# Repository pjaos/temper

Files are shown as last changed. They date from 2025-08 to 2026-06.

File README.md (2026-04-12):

# Temper

A Python tool for discovering temperature and humidity sensor units on the local LAN, recording their readings to a SQLite database, and visualising the data through a web-based dashboard.

---

## Overview

Temper consists of two programs that work together along with the ESP32 based hardware.

- **`temper_db`** — a background collector that listens for sensor broadcasts on the LAN and saves every reading to a local SQLite database.
- **`temper_gui`** — a browser-based dashboard (built with [NiceGUI](https://nicegui.io) and [Plotly](https://plotly.com/python/)) for plotting temperature and humidity data across any time range.

The two programs are independent. `temper_db` can run continuously as a background service while `temper_gui` is started on demand to view the data.

---

## Hardware

Temper is designed to work with TEMPER-branded sensor units that broadcast JSON payloads over UDP on the local network. Each unit reports up to four independent temperature/humidity sensor channels, along with system telemetry (RAM, disk, uptime, RSSI, battery voltage, etc.).

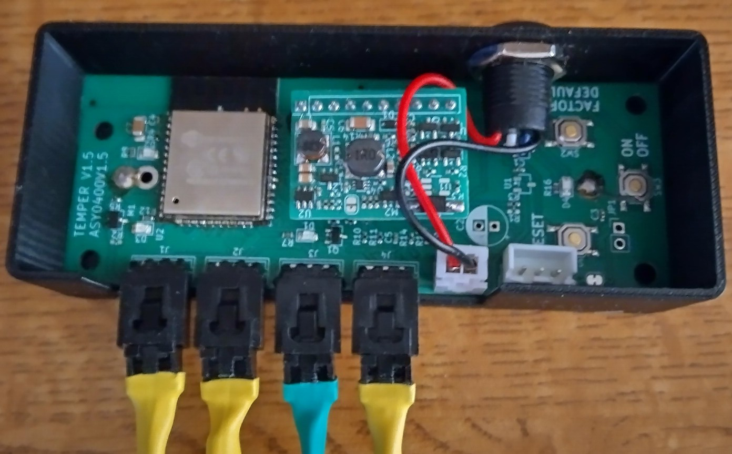
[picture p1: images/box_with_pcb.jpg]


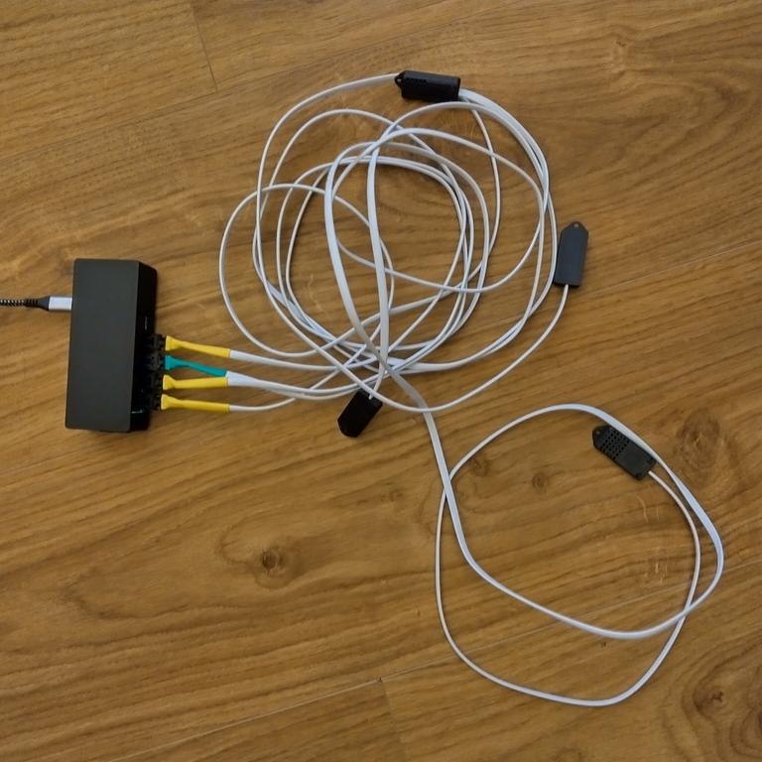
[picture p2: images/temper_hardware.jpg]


Details of the hardware including kicad schematic, PCB and BOM can be found in the hardware folder.

This hardware runs a micropython program which can be found in software/mcu folder. It listens on **UDP port 2934** and responds to *Are You There* broadcast messages with the status (temperature/humidity etc).

---

## Requirements

- Python 3.10 or later

---

## Installation

The python wheel installer file can be found in the linux folder.

### Using the bundled installer

```bash
python3 install.py linux/temper-<version>-py3-none-any.whl
```

This creates a virtual environment, installs all dependencies, and adds the `temper_db` and `temper_gui` commands to your PATH. A temper_gui launch icon is also added to you desktop.

---

## Usage

### Collector — `temper_db`

Discovers TEMPER hardware units on the local LAN and writes every received reading to the database.

```bash
python -m temper.temper_db [options]
```

| Option | Description |
|---|---|
| `-d`, `--debug` | Enable debug logging (prints each received JSON payload). |
| `-a ADDRESS`, `--address ADDRESS` | Only record data from the unit at this IP address. If omitted, all units found are recorded. |
| `-s SECONDS`, `--seconds SECONDS` | Interval between *Are You There* broadcasts (default: 10 s). |
| `--enable_auto_start` | Register the tool to start on system boot |
| `--disable_auto_start` | Un-register the tool to start on system boot |
| `--check_auto_start` | Check the running status |

**Example — record all units, broadcast every 30 seconds:**

```bash
temper_db --seconds 30
```

**Example — record only one unit:**

```bash
temper_db --address 192.168.0.99
```

**Example Running as a service**

Use the built-in boot manager to have the tool start automatically (Linux only):

```bash
temper_db --seconds 30 --enable_auto_start
```

Press **Ctrl-C** to stop.

### Dashboard — `temper_gui`

Starts a local web server and opens the dashboard in the default browser.

```bash
temper_gui [options]
```

| Option | Description |
|---|---|
| `-d`, `--debug` | Enable debug logging. |
| `-p PORT`, `--port PORT` | TCP port for the NiceGUI web server (default: 8085). |
| `-n`, `--no_web_launch` | Start the server without opening a browser tab automatically. |
| `--enable_auto_start` | Register the tool to start on system boot |
| `--disable_auto_start` | Un-register the tool to start on system boot |
| `--check_auto_start` | Check the running status |

**Browser Example**

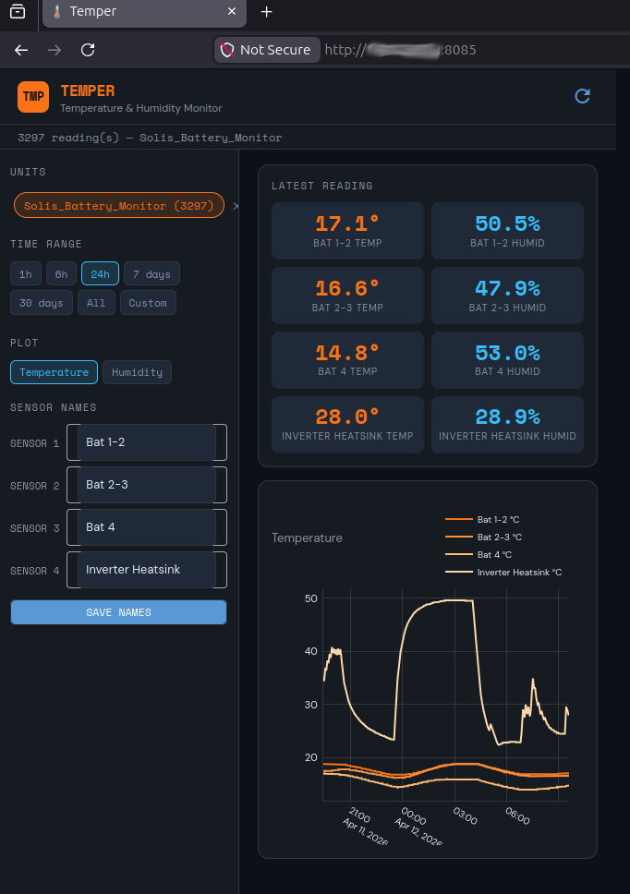
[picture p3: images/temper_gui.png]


**Example — start on a non-default port:**

```bash
temper_gui --port 9090
```

**Example — headless server (access from another device):**

```bash
temper_gui --no_web_launch
```

Then navigate to `http://<host-ip>:8085` from any browser on the same network, including a mobile phone.

**Example Running as a service**

Use the built-in boot manager to have the tool start automatically (Linux only):

```bash
temper_gui -n --enable_auto_start
```

---

## Dashboard features

The dashboard is responsive and works on both desktop and mobile browsers.

**Sidebar controls**

- **Units** — chips showing every known unit and its total reading count. Click to select a unit and load its data.
- **Time Range** — preset buttons (1h, 6h, 24h, 7 days, 30 days, All) plus a Custom option with date pickers.
- **Plot** — switch between Temperature and Humidity views.
- **Sensor Names** — rename each of the four sensor channels (e.g. *Living Room*, *Loft*, *Outside*). Names are saved to `sensor_names.json` and persist across restarts. The chart legend and stat tiles update immediately on save.

**Main area**

- **Latest Reading** — a tile grid showing the most recent temperature and humidity value for each active sensor on the selected unit.
- **Chart** — an interactive Plotly time-series plot. Hover over any point to see values for all sensors at that timestamp. Zoom and pan with standard Plotly controls.

---

## Data storage

The database and sensor name configuration are stored in:

| Platform | Path |
|---|---|
| Linux / macOS (XDG) | `~/.config/temper/` |
| Linux / macOS (fallback) / Windows | `~/.temper/` |

Files created:

| File | Contents |
|---|---|
| `temper_sensor_data.db` | SQLite database containing all sensor readings. |
| `sensor_names.json` | User-defined display names for the four sensor channels. |

### Database schema

Two tables are used:

**`units`** — one row per discovered device.

| Column | Type | Description |
|---|---|---|
| `id` | INTEGER | Primary key. |
| `unit_name` | TEXT | Unique device identifier (e.g. `TEMPER_DEV`). |
| `device_type` | TEXT | Always `SENSOR` for TEMPER hardware. |
| `product_id` | TEXT | Always `TEMPER`. |
| `ip_address` | TEXT | Last seen IP address. |
| `os` | TEXT | Firmware OS (e.g. `MicroPython`). |
| `group_name` | TEXT | Optional group label from the device. |
| `service_list` | TEXT | Services advertised by the device. |
| `first_seen` | TIMESTAMP | UTC timestamp of first contact. |
| `last_seen` | TIMESTAMP | UTC timestamp of most recent contact. |

**`sensor_readings`** — one row per received broadcast.

| Column | Type | Description |
|---|---|---|
| `id` | INTEGER | Primary key. |
| `unit_id` | INTEGER | Foreign key → `units.id`. |
| `recorded_at` | TIMESTAMP | UTC time the reading was received. |
| `rx_time_secs` | REAL | Unix timestamp from the device itself. |
| `uptime_seconds` | INTEGER | Device uptime in seconds. |
| `sensor_1_temp` … `sensor_4_temp` | REAL | Temperature readings in °C. |
| `sensor_1_humidity` … `sensor_4_humidity` | REAL | Relative humidity readings in %RH. |
| `param_3v3` | REAL | 3.3 V rail voltage. |
| `param_vbat` | REAL | Battery voltage. |
| `param_rssi` | REAL | Wi-Fi signal strength in dBm. |
| `param_board_temp` | REAL | On-board temperature sensor reading. |
| `ram_*`, `disk_*` | INTEGER | RAM and disk usage telemetry. |

### Maintenance

To delete readings older than 90 days from a Python session:

```python
from temper.temper_db import TemperDB
from unittest.mock import MagicMock
db = TemperDB.__new__(TemperDB)
db._uio = MagicMock(); db._options = None
db._db_file = TemperDB.GetDBFile()
deleted = db.prune_readings_older_than(days=90)
print(f"Deleted {deleted} rows")
```

---

## Running tests

Tests use [pytest](https://pytest.org). From the client directory:

```bash
./run_tests.sh
```

The test suite covers all database operations (`TemperDB`) including table creation, unit upsert, reading insertion, time-range filtering, latest-reading queries, and data pruning. No network access or real hardware is required.

---

## Project structure

```
temper/software/client/
├── src/
│   └── temper/
│       ├── temper_db.py        # Collector + database layer
│       └── temper_gui.py       # NiceGUI web dashboard
└── tests/
    └── test_temper_db.py       # pytest test suite
```

---

## Licence

See `LICENSE` in the repository root.

## Author

Paul Austen — [pjaos@gmail.com](mailto:pjaos@gmail.com)

## Acknowledgements

Development of this project was assisted by [Claude](https://claude.ai) (Anthropic's AI assistant),
which contributed to code review, bug identification, test generation, and this documentation.

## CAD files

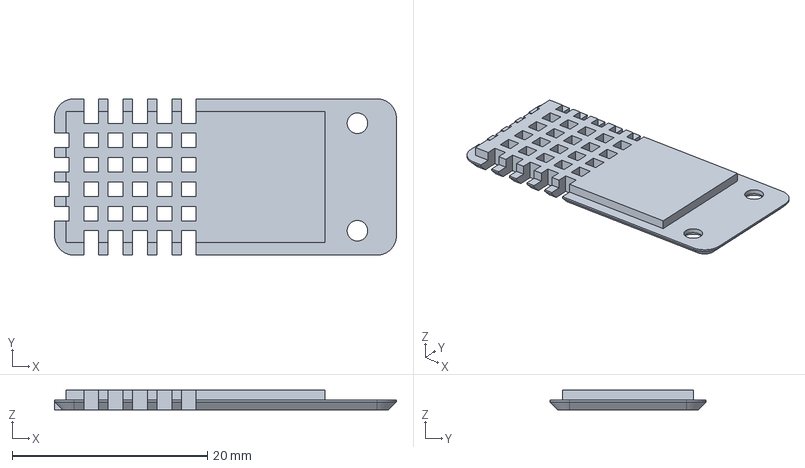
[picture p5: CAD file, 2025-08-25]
hardware/3d_printed_parts/dht22_temp_senor_case/dht22_box_top.FCStd
35.0 x 16.0 x 2.00 mm

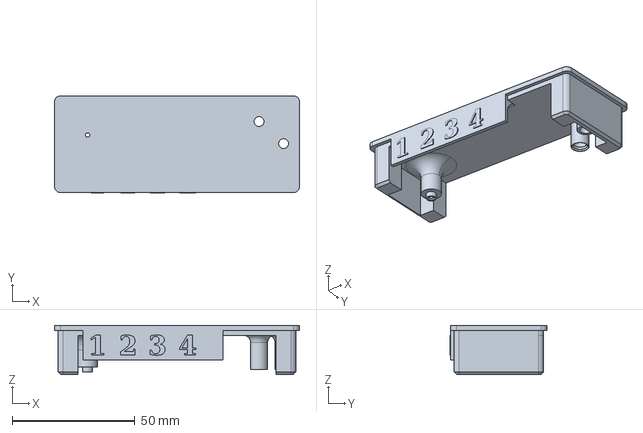
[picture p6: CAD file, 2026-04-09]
hardware/3d_printed_parts/temper_case/no_bat_top.FCStd
100.0 x 39.8 x 20.0 mm

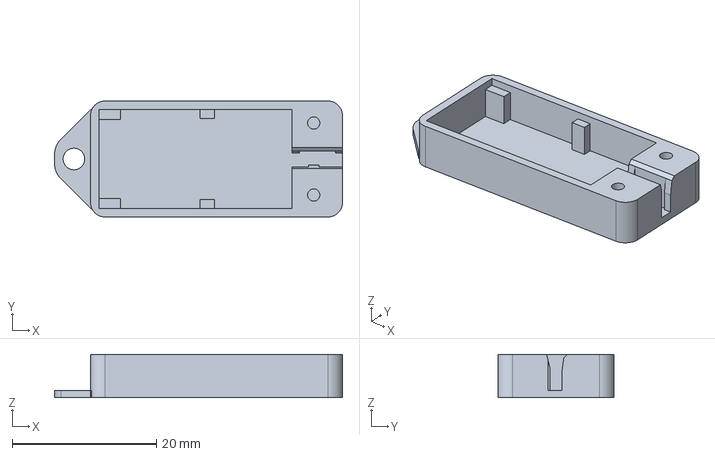
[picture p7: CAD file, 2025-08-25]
hardware/3d_printed_parts/dht22_temp_senor_case/dht22_box.FCStd
40.0 x 16.1 x 6.00 mm

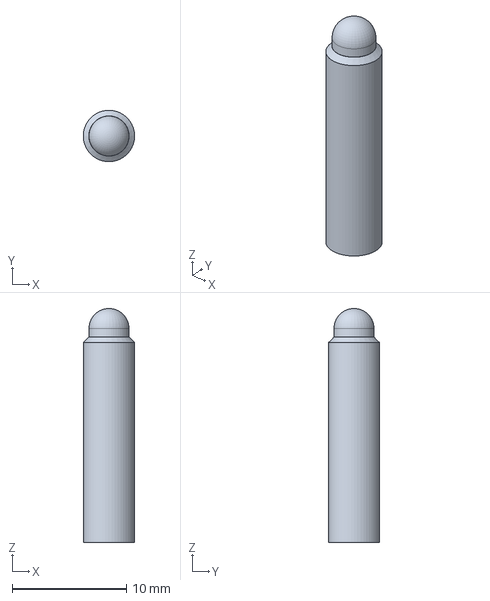
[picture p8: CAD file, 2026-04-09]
hardware/3d_printed_parts/temper_case/button.FCStd
4.50 x 4.50 x 20.5 mm

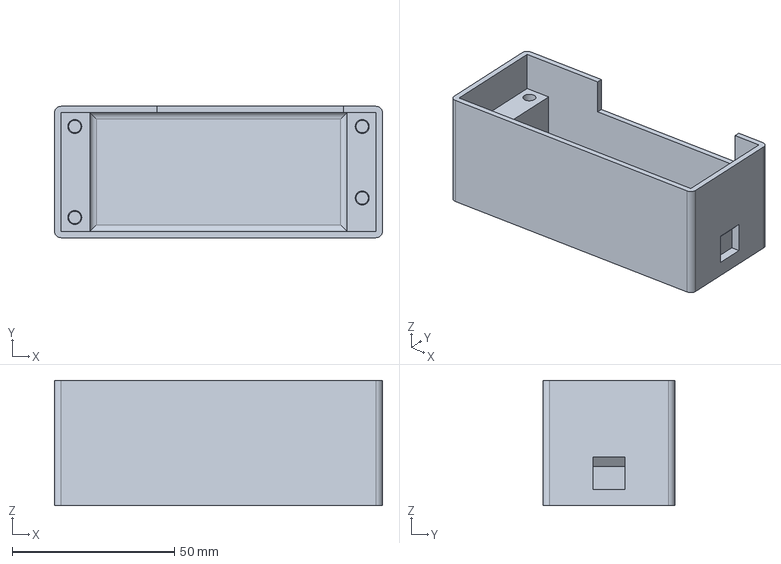
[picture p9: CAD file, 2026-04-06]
hardware/3d_printed_parts/temper_case/base.FCStd
101.0 x 40.5 x 38.5 mm

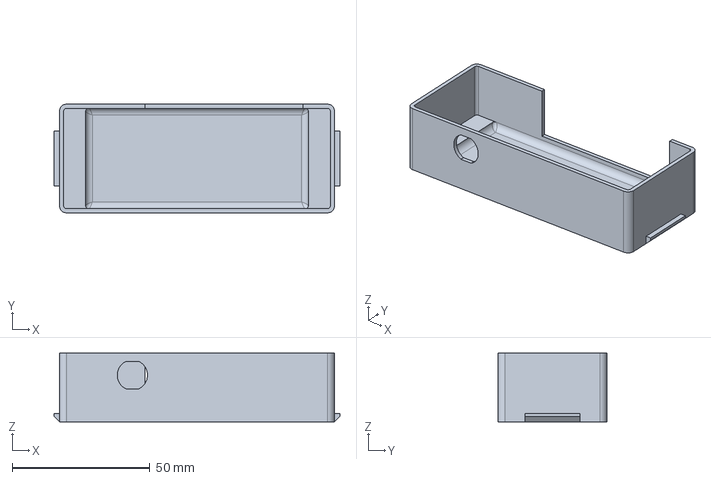
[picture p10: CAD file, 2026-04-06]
hardware/3d_printed_parts/temper_case/no_bat_base.FCStd
104.0 x 39.5 x 25.0 mm

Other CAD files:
hardware/3d_printed_parts/dht22_temp_senor_case/dht22_box.3mf
hardware/3d_printed_parts/dht22_temp_senor_case/dht22_box_top.3mf
hardware/3d_printed_parts/temper_case/base.3mf
hardware/3d_printed_parts/temper_case/button.3mf
hardware/3d_printed_parts/temper_case/no_bat_base.3mf
hardware/3d_printed_parts/temper_case/no_bat_top.3mf

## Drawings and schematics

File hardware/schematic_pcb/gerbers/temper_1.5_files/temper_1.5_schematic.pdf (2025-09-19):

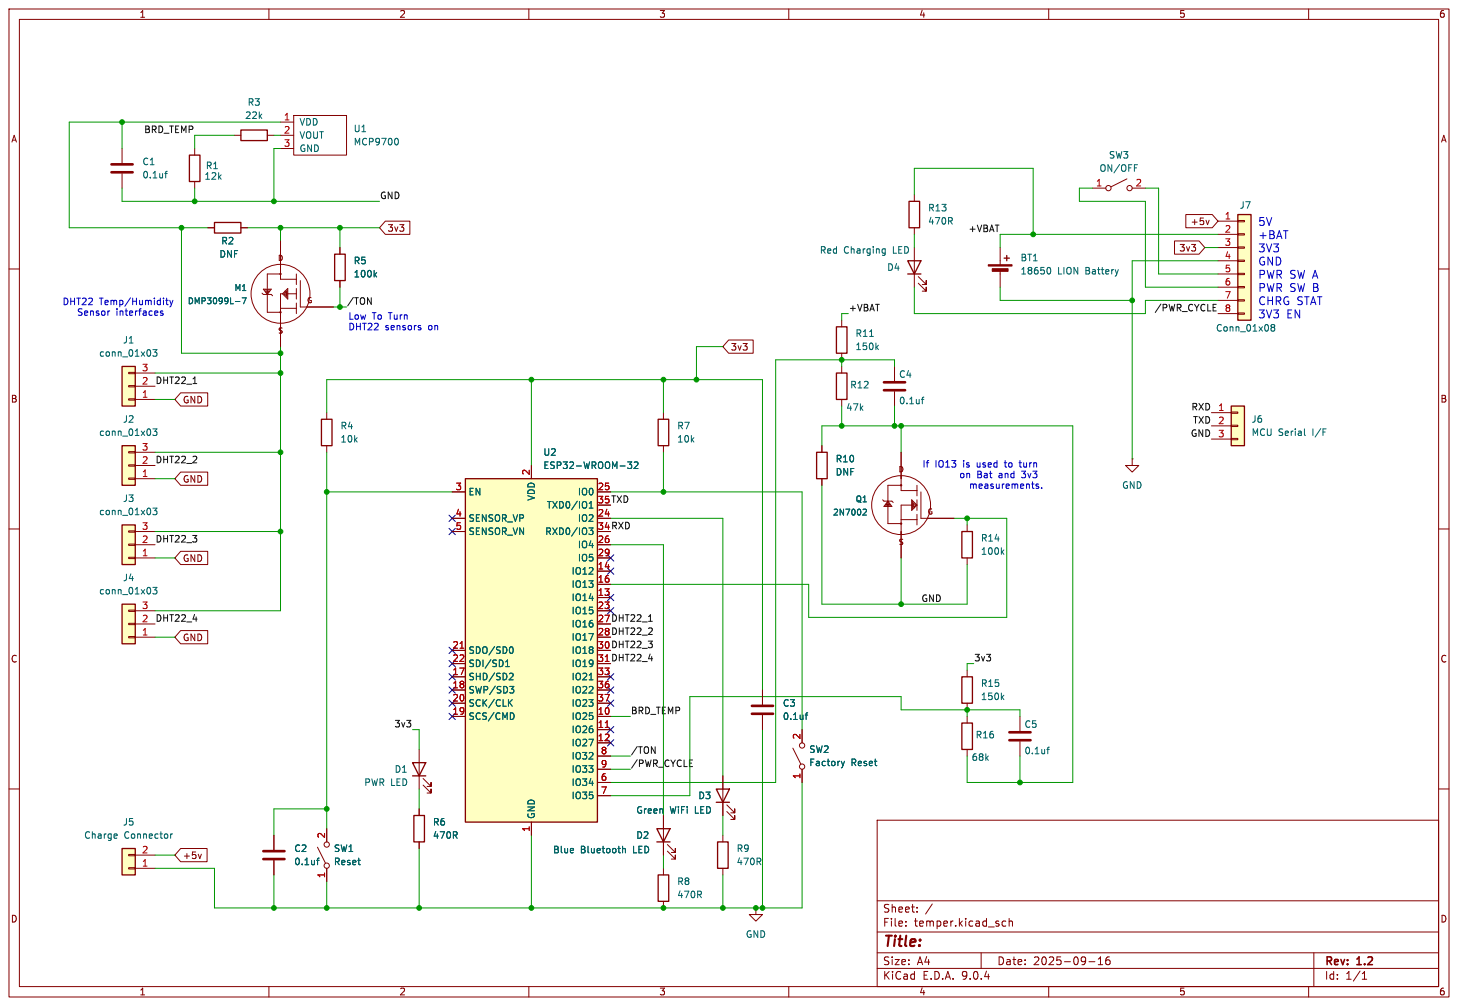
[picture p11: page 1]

If IO13 is used to turn

Id: 1/1 Title: File: temper.kicad_sch Sheet: / C2

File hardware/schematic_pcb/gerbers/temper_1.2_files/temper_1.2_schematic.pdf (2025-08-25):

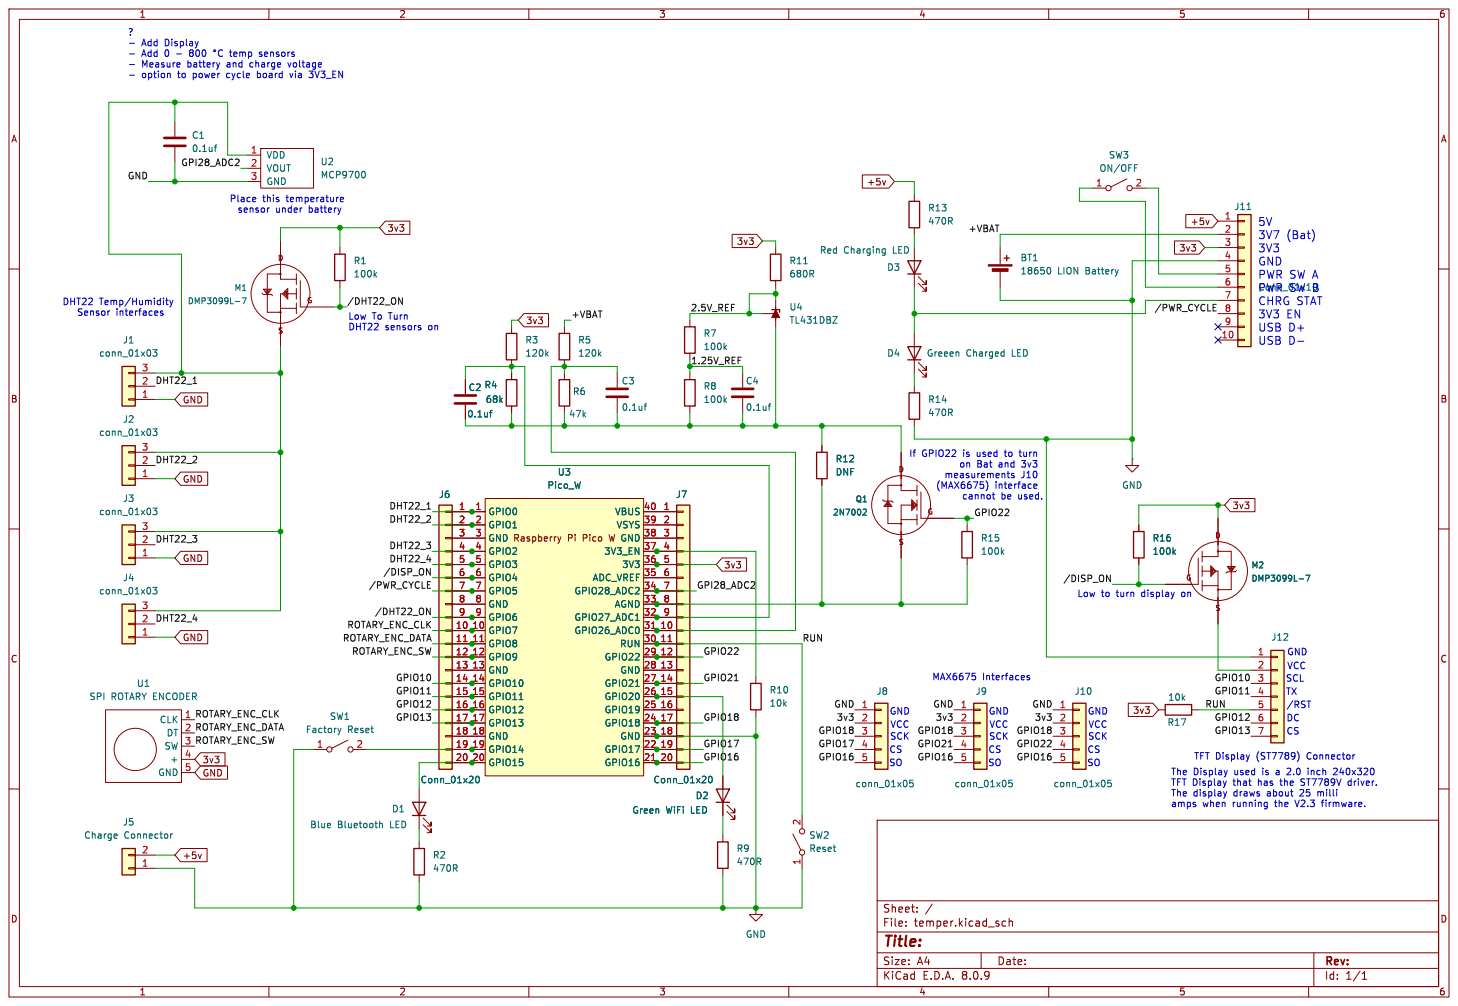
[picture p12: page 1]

- Add Display
- Add 0 - 800 þÿ°Ctemp sensors
- Measure battery and charge voltage
- option to power cycle board via 3V3_EN
S M1 DMP3099L-7 1

If GPIO22 is used to turn

cannot be used. CS

11 11 | 11 11
12 12 | 12 12
13 13 | 13 13
14 14 | 14 14
15 15 | 15 15

4 GND 5 U1 SPI ROTARY ENCODER

The Display used is a 2.0 inch 240x320 TFT Display that has the ST7789V driver. The display draws about 25 milli amps when running the V2.3 firmware.

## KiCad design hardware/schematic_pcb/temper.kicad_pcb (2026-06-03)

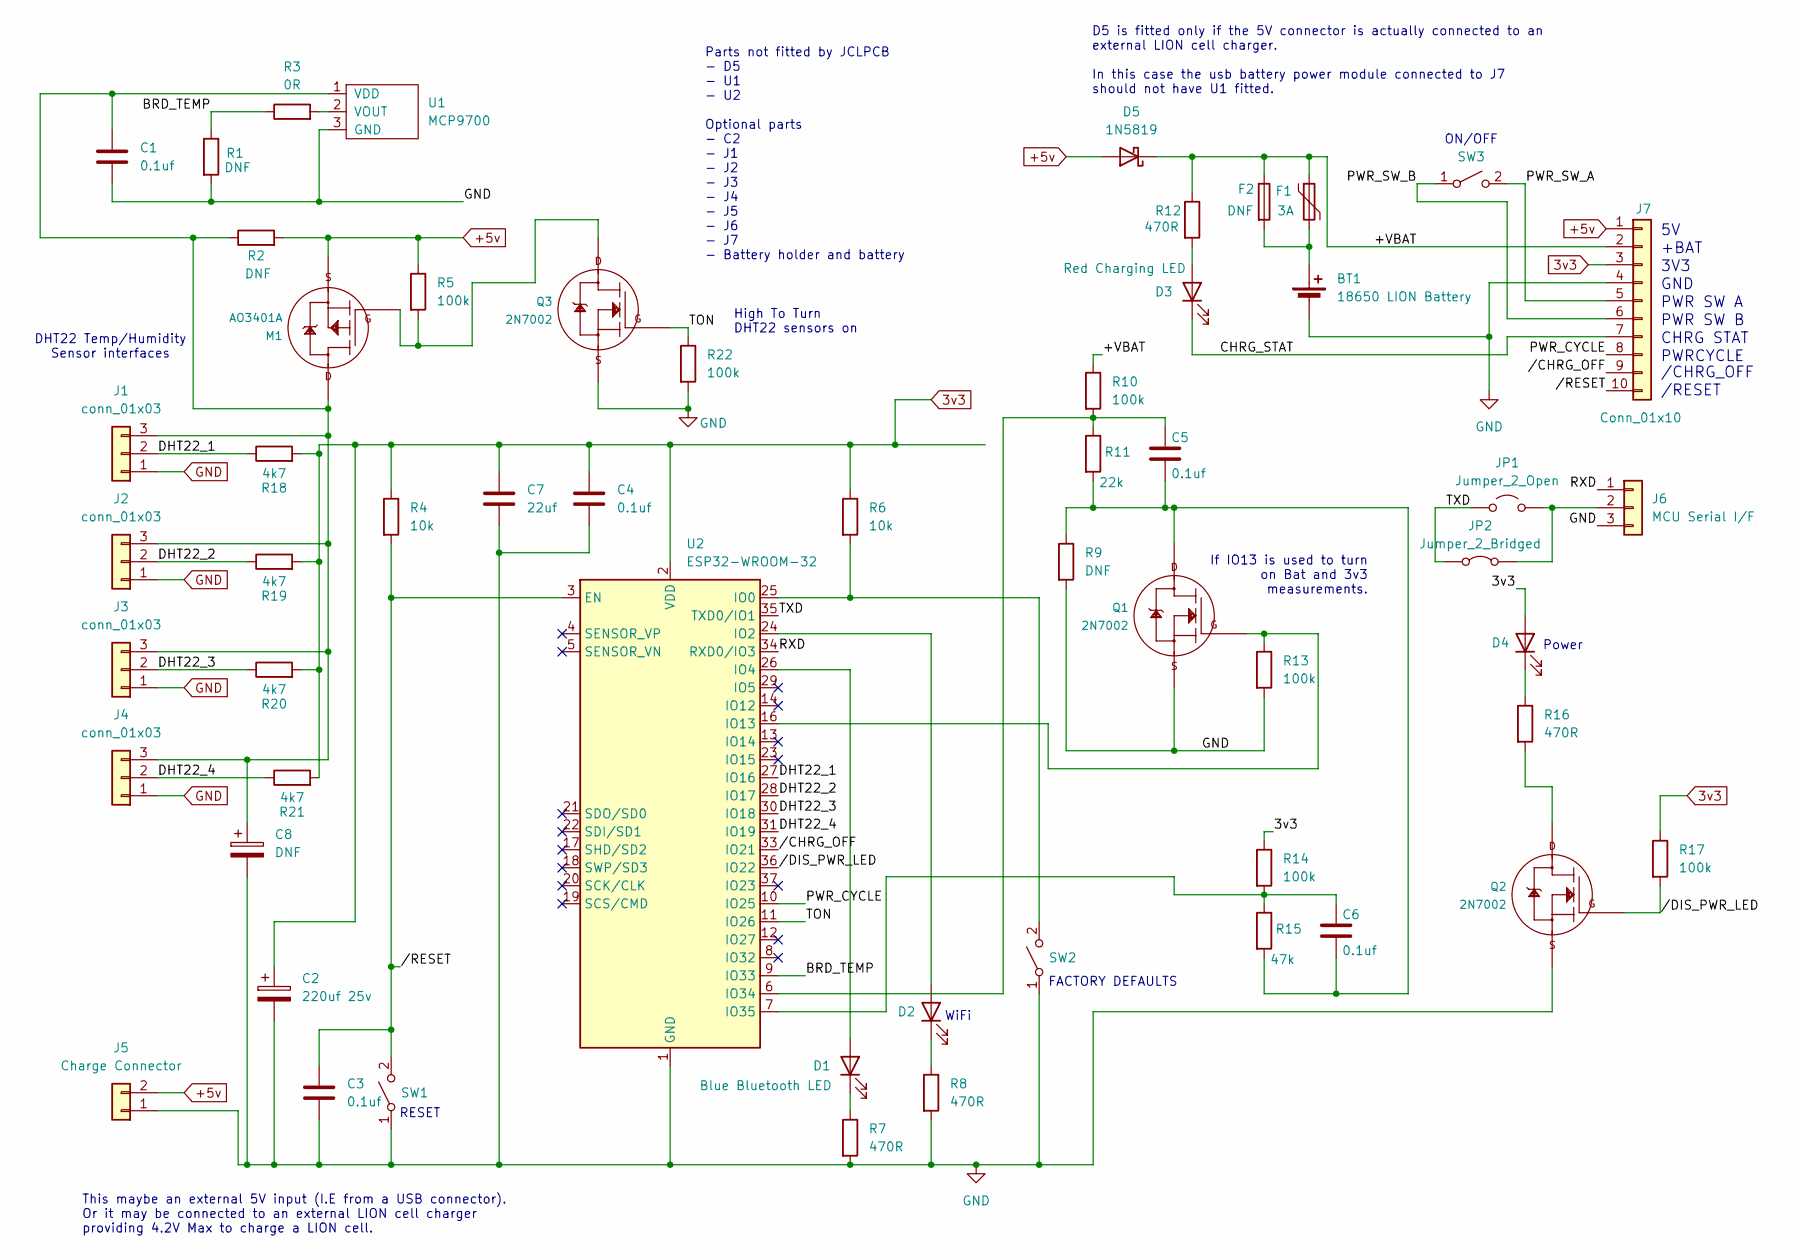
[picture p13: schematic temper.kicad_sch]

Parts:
BT1: 18650 LION Battery; 18650_26700_battery_holder
C1, C3, C4, C5, C6: 0.1uf; C_0402_1005Metric_Pad0.74x0.62mm_HandSolder; LCSC C307331
C2: 220uf 25v; CP_Radial_D6.3mm_P2.50mm
C7: 22uf; C_1206_3216Metric_Pad1.33x1.80mm_HandSolder; LCSC C12891
C8: DNF; CP_Radial_D5.0mm_P2.50mm
D1: Blue Bluetooth LED; LED_0805_2012Metric_Pad1.15x1.40mm_HandSolder; LCSC C2296
D2, D4: GreenLED; LED_0805_2012Metric_Pad1.15x1.40mm_HandSolder; LCSC C2297
D3: Red Charging LED; LED_0805_2012Metric_Pad1.15x1.40mm_HandSolder; LCSC C84256
D5: 1N5819; D_SMA_Handsoldering
F1: 3A; PTC_23mm_3mm_10.2mm_wire_spacing
F2: DNF; Scherter_OMT125
J1, J2, J3, J4: conn_01x03; JST_EH_B3B-EH-A_1x03_P2.50mm_Vertical
J5: Charge Connector; JST_EH_B2B-EH-A_1x02_P2.50mm_Vertical
J6: MCU Serial I/F; JST_EH_B3B-EH-A_1x03_P2.50mm_Vertical
J7: Conn_01x10; PinHeader_1x10_P2.54mm_Vertical
JP1: Jumper_2_Open; PinHeader_1x02_P2.54mm_Vertical
JP2: Jumper_2_Bridged; SolderJumper-2_P1.3mm_Bridged_RoundedPad1.0x1.5mm
M1: AO3401A; SOT-23-3; LCSC C15127
Q1, Q2, Q3: 2N7002; SOT-23-3; LCSC C8545
R1, R2, R9: DNF; R_0402_1005Metric_Pad0.72x0.64mm_HandSolder
R3: 0R; R_0402_1005Metric_Pad0.72x0.64mm_HandSolder; LCSC C17168
R4, R6: 10k; R_0402_1005Metric_Pad0.72x0.64mm_HandSolder; LCSC C25744
R5, R10, R13, R14, R17, R22: 100k; R_0402_1005Metric_Pad0.72x0.64mm_HandSolder; LCSC C25741
R7, R8, R12, R16: 470R; R_0402_1005Metric_Pad0.72x0.64mm_HandSolder; LCSC C23179
R11: 22k; R_0402_1005Metric_Pad0.72x0.64mm_HandSolder; LCSC C25768
R15: 47k; R_0402_1005Metric_Pad0.72x0.64mm_HandSolder; LCSC C25792
R18, R19, R20, R21: 4k7; R_0402_1005Metric_Pad0.72x0.64mm_HandSolder; LCSC C25900
SW1, SW2, SW3: tactsw; SW_SPST_SKQG_WithoutStem; LCSC C318884
U1: MCP9700; SOT-23-3
U2: ESP32-WROOM-32

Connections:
3v3: C2.1, C4.1, C7.1, D4.2 (A), J7.3, R4.1, R6.1, R14.1, R17.1, R18.2, R19.2, R20.2, R21.2, U2.2 (VDD)
+5v: D5.2 (A), J5.2, J7.1, M1.2 (S1), R2.2, R5.1
/+VBAT: D5.1 (K), F1.1, F2.1, J7.2, R10.1, R12.1
/BRD_TEMP: R1.1, R3.1, U2.9 (IO33)
/CHRG_STAT: D3.1 (K), J7.7
/DHT22_1: J1.2, R18.1, U2.27 (IO16)
/DHT22_2: J2.2, R19.1, U2.28 (IO17)
/DHT22_3: J3.2, R20.1, U2.30 (IO18)
/DHT22_4: J4.2, R21.1, U2.31 (IO19)
/PWR_CYCLE: J7.8, U2.10 (IO25)
/PWR_SW_A: J7.5, SW3.2 (B)
/PWR_SW_B: J7.6, SW3.1 (A)
/RXD: J6.1, U2.34 (RXD0/IO3)
/TON: Q3.1 (G), R22.1, U2.11 (IO26)
/TXD: JP1.1 (A), JP2.1 (A), U2.35 (TXD0/IO1)
//CHRG_OFF: J7.9, U2.33 (IO21)
//DIS_PWR_LED: Q2.1 (G), R17.2, U2.36 (IO22)
//RESET: C3.1, J7.10, R4.2, SW1.2 (B), U2.3 (EN)
GND: BT1.2 (-), C1.2, C2.2, C3.2, C4.2, C7.2, C8.2, J1.1, J2.1, J3.1, J4.1, J5.1, J6.3, J7.4, Q1.2 (S), Q2.2 (S), Q3.2 (S), R1.2, R7.2, R8.2, R9.2, R13.2, R22.2, SW1.1 (A), SW2.1 (A), U1.3 (GND), U2.1 (GND), U2.15 (GND), U2.38 (GND), U2.39 (GND)
unnamed: BT1.1 (+), F1.2, F2.2
unnamed: D1.2 (A), U2.26 (IO4)
unnamed: D1.1 (K), R7.1
unnamed: D2.2 (A), U2.24 (IO2)
unnamed: D2.1 (K), R8.1
unnamed: D3.2 (A), R12.2
unnamed: D4.1 (K), R16.1
unnamed: C1.1, C8.1, J1.3, J2.3, J3.3, J4.3, M1.3 (D1), R2.1, U1.1 (VDD)
unnamed: J6.2, JP1.2 (B), JP2.2 (B)
unnamed: M1.1 (G1), Q3.3 (D), R5.2
unnamed: C5.2, C6.2, Q1.3 (D), R9.1, R11.2, R15.2
unnamed: Q1.1 (G), R13.1, U2.16 (IO13)
unnamed: Q2.3 (D), R16.2
unnamed: R6.2, SW2.2 (B), U2.25 (IO0)
unnamed: R3.2, U1.2 (VOUT)
unnamed: C5.1, R10.2, R11.1, U2.6 (IO34)
unnamed: C6.1, R14.2, R15.1, U2.7 (IO35)

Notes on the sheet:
+BAT
RESET
If IO13 is used to turn on Bat and 3v3 measurements.
CHRG STAT
Parts not fitted by JCLPCB - D5 - U1 - U2 Optional parts - C2 - J1 - J2 - J3 - J4 - J5 - J6 - J7 - Battery holder and battery
/RESET
Power
High To Turn DHT22 sensors on
/CHRG_OFF
This maybe an external 5V input (I.E from a USB connector). Or it may be connected to an external LION cell charger providing 4.2V Max to charge a LION cell.
FACTORY DEFAULTS
GND
PWR SW A
PWR SW B
DHT22 Temp/Humidity Sensor interfaces
ON/OFF
3V3
PWRCYCLE
WiFi
D5 is fitted only if the 5V connector is actually connected to an external LION cell charger. In this case the usb battery power module connected to J7 should not have U1 fitted.

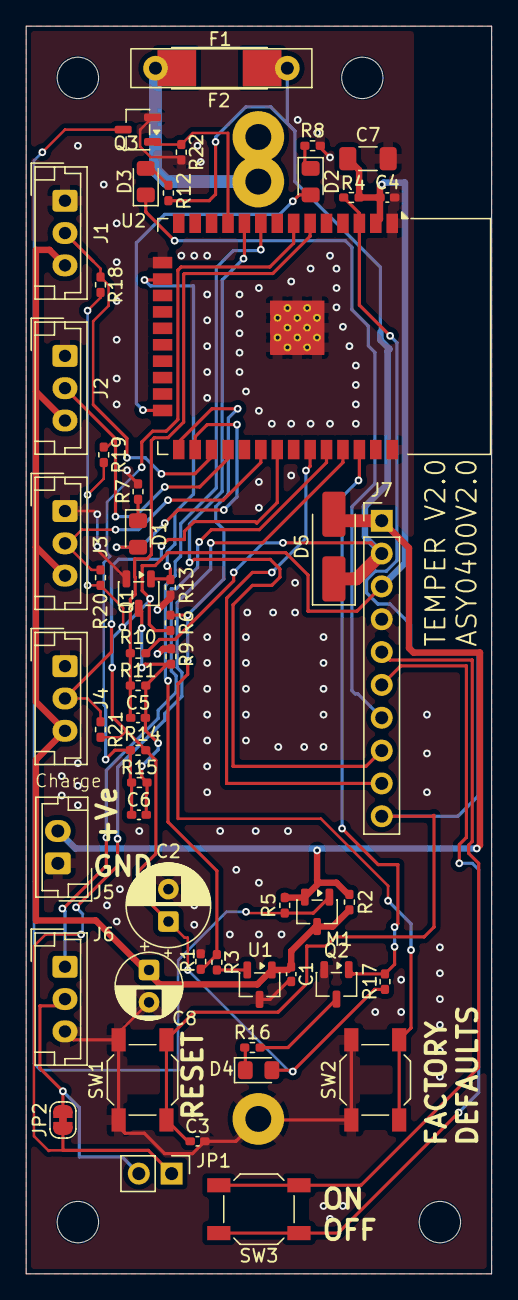
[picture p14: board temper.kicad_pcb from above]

Board: 2 copper layers, 36.0 x 96.5 mm, 60 parts (0 on the bottom side), 36 nets.

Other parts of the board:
H1, H2, H3, H4: MountingHole_3.2mm_M3

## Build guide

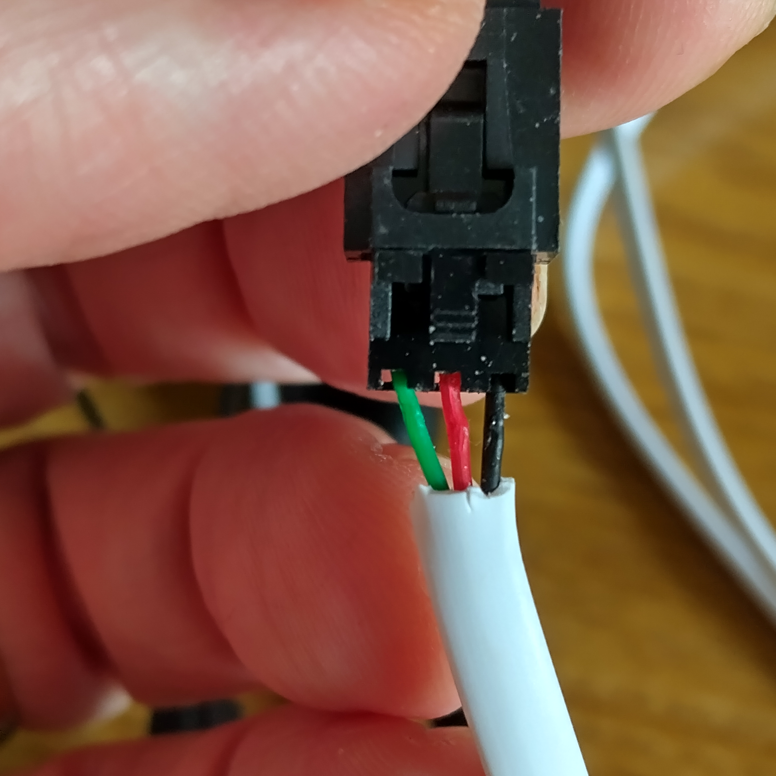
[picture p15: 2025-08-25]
doc/molex_2543_connector_wiring.jpg

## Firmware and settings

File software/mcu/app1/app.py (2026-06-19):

import asyncio
import gc
from time import time
import sys, io

from lib.uo import UO
from lib.config import MachineConfig
from lib.ydev import YDev
from lib.base_machine import BaseMachine

from machine import ADC, Pin
import dht

SHOW_MESSAGES_ON_STDOUT = True  # Turning this off will stop messages being sent on the serial port and will reduce CPU usage.
WDT_TIMEOUT_MSECS = 8300        # Note that 8388 is the max WD timeout value on pico W hardware.


class ThisMachineConfig(MachineConfig):
    """@brief Defines the config specific to this machine."""

    # Note that
    # MachineConfig.RUNNING_APP_KEY and
    # MachineConfig.WIFI_KEY will added automatically so we only need
    # to define keys that are specific to this machine type here.

    DEFAULT_CONFIG = {YDev.ACTIVE: True,
                      YDev.AYT_TCP_PORT_KEY: 2934,               # The UDP port we expect to receive an AYT UDP broadcast message
                      YDev.OS_KEY: "MicroPython",
                      YDev.UNIT_NAME_KEY: "TEMPER_DEV",          # This can be used to identify device, probably user configurable.
                      YDev.PRODUCT_ID_KEY: "TEMPER",             # This is fixed for the product, probably during MFG.
                      YDev.DEVICE_TYPE_KEY: "SENSOR",            # This is fixed for the product, probably during MFG.
                      YDev.SERVICE_LIST_KEY: "web:80",           # A service name followed by the TCPIP port number this device presents the service on.
                      YDev.GROUP_NAME_KEY: ""                    # Used put devices in a group for mild isolation purposes.
                      }

    def __init__(self):
        super().__init__(ThisMachineConfig.DEFAULT_CONFIG)


async def start(runningAppKey, configFilename):
    """@brief The app entry point.
       @param runningAppKey The KEY in the config dict that holds the current running app.
       @param configFilename The name of the config file. This sits in / on flash."""
    MachineConfig.RUNNING_APP_KEY = runningAppKey
    MachineConfig.CONFIG_FILENAME = configFilename
    file_path = __file__
    if file_path.startswith('app1'):
        active_app = 1

    elif file_path.startswith('app2'):
        active_app = 2

    else:
        raise Exception(f"App path not /app1 or /app2: {file_path}")

    if SHOW_MESSAGES_ON_STDOUT:
        uo = UO(enabled=True, debug_enabled=True)
        uo.info("Started app")
        uo.info("Running app{}".format(active_app))
    else:
        uo = None

    machine_config = ThisMachineConfig()
    this_machine = ThisMachine(uo, machine_config)
    this_machine.start()


class ThisMachine(BaseMachine):
    """@brief Implement functionality required by this project."""

    ADC_CODES_TO_MV             = 14508  # Arrived at empirically by measuring the ADC voltage @ 25C
    MCP9700_VOUT_0C             = 0.5
    MCP9700_TC                  = 0.01

    PARAM_3V3 = "PARAM_3V3"
    PARAM_VBAT = "PARAM_VBAT"
    PARAM_BOARD_TEMP = "PARAM_BOARD_TEMP"
    PARAM_SENSOR_1_TEMP = "PARAM_SENSOR_1_TEMP"
    PARAM_SENSOR_1_HUMIDITY = "PARAM_SENSOR_1_HUMIDITY"
    PARAM_SENSOR_2_TEMP = "PARAM_SENSOR_2_TEMP"
    PARAM_SENSOR_2_HUMIDITY = "PARAM_SENSOR_2_HUMIDITY"
    PARAM_SENSOR_3_TEMP = "PARAM_SENSOR_3_TEMP"
    PARAM_SENSOR_3_HUMIDITY = "PARAM_SENSOR_3_HUMIDITY"
    PARAM_SENSOR_4_TEMP = "PARAM_SENSOR_4_TEMP"
    PARAM_SENSOR_4_HUMIDITY = "PARAM_SENSOR_4_HUMIDITY"
    PARAM_RSSI = "PARAM_RSSI"
    EXCEPTION_TEXT = "EXCEPTION_TEXT"
    DETECTED_SENSOR_LIST = "DETECTED_SENSOR_LIST"

    MIN_DHT22_TEMP = -40.0
    MAX_DHT22_TEMP = 80.0

    def __init__(self, uo, machine_config):
        super().__init__(uo, machine_config)
        self._startTime = time()
        self._ydev = None
        self._sensor_power_pin = Pin(26, Pin.OUT, value=0)
        self._sensor_read_error_count=0

        # Enable watchdog timer here if required.
        # If the WiFi goes down then we can
        # drop out to the REPL prompt.
        # The WDT will then trigger a reboot.
        # self._wdt = WDT(timeout=WDT_TIMEOUT_MSECS)

        # Ensure the device name is present in the machine config
        # This is the same value that used to be hard coded.
        if not self._machine_config.is_parameter(YDev.UNIT_NAME_KEY):
            self._machine_config.set(YDev.UNIT_NAME_KEY, "TEMPER_DEV")

    def start(self):
        self.show_ram_info()

        # Connect this machine to a WiFi network.
        # Note that the WiFi setup claims two GPIO pins. See _sta_connect_wifi doc for more info.
        self._sta_connect_wifi(wifi_setup_gpio=0, wifi_led_gpio=2, bluetooth_led_gpio=4)

        # Start task that looks for user press of the reset to defaults button press
        asyncio.create_task(self._check_factory_Defaults_task())

        # Task that will return JSON messages to the YDev server.
        self._ydev = YDev(self._machine_config)
        asyncio.create_task(self._ydev.listen())

        # Run the web server. This is used for upgrades and also to present
        # a local webserver to allow users to interact with the device.
        from lib.webserver import WebServer
        self._web_server = WebServer(self._machine_config,
                               self._startTime,
                               uo=self._uo)

        # Call the app task to execute your projects functionality.
        asyncio.create_task(self.app_task())

        self._web_server.run()

    async def power_cycle_temp_sensors(self, delay=10.0):
        # Set TON low to remove power to the temp sensors
        self._sensor_power_pin.value(0)
        await asyncio.sleep(delay)
        # Set TON high to apply power to the temp sensors
        self._sensor_power_pin.value(1)

    async def _read_sensor(self, sensor, multi_read_delay=5, max_retry=3):
        """@return [temp, humidity] on success, or None if recovery was triggered."""
        read_count = 0
        while True:
            try:
                self.pat_wdt()
                gc.collect()
                gc.disable()
                try:
                    sensor.measure()
                    temp = sensor.temperature()
                    humidity = sensor.humidity()
                    if (ThisMachine.MIN_DHT22_TEMP <= temp <= ThisMachine.MAX_DHT22_TEMP
                            and 0 <= humidity <= 100):
                        return [temp, humidity]          # <-- the missing return
                except Exception:
                    pass

            finally:
                gc.enable()                              # runs even on the return above

            read_count += 1
            if read_count > max_retry:
                Pin(25, Pin.OUT, value=1)                # trigger recovery
                return None                              # don't spin; let the cycle/reset take over
            await asyncio.sleep(multi_read_delay)
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

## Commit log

2025-08-25 Add initial schematic/pcb
    [dht22_box.3mf, dht22_box.FCStd, dht22_box_top.3mf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]
2025-09-16 First PCB using RPi Pico working
    [temper.kicad_pcb, temper.kicad_sch]
2025-09-19 V1.2 using an ESP32 rather than a RPi Pico W. The ESP32 can handle low power modes better than the RPi Pico W.
    [temper-B_Cu.gbl, temper-B_Mask.gbs, temper-B_Paste.gbp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]
2025-10-06 - Move ADC2 pins as ADC2 cannot be used with WiFi. - Add power up reset controller to ensure MCU boots after powercyle event.
    [temper.kicad_pcb, temper.kicad_sch]
2025-10-13 Bump PCB to V1.4 to accept the 26700 Sodium ION battery.
    [temper.kicad_pcb, temper.kicad_sch]
2025-11-10 Add 1.5 HW design.
    [temper.kicad_pcb, temper.kicad_sch]
2026-03-23 Update to add D5.
    [temper.kicad_pcb, temper.kicad_sch]
2026-03-23 Update JCLPCB not fitted parts.
    [temper.kicad_sch]
2026-04-06 - Set product ID to TEMPER - Add RSSI to stats - Add board temp to stats - Ensure all connected sensors are read
2026-04-06 Addd new location for 3d printed parts.
    [base.3mf, base.FCStd, dht22_box.3mf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]
2026-04-06 Ignore the gerbers folder.
2026-04-07 Add port numbers to sensor ports.
    [no_bat_top.3mf, no_bat_top.FCStd]
2026-04-07 Add printable file that adds port numbers to case.
    [no_bat_top.3mf]
2026-04-08 Add updated python wheel
2026-04-09 Update top to include light pipe for wifi status and button to setup wifi.
    [button.3mf, button.FCStd, no_bat_top.3mf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]
2026-04-09 Add dimensions to the Wifi LED and the wifi setup button to the Kicad PCB.
    [temper.kicad_pcb]
2026-04-09 Add on/off button to case.
    [button.3mf, no_bat_top.3mf, no_bat_top.FCStd]
2026-04-09 Add location of on/off button to pcb
    [temper.kicad_pcb]
2026-04-09 Pat watchdog while reading sensors.
2026-04-09 Check factory defaults button every 0.1 seconds
2026-04-09 Change default sensor poll time to once every 60 seconds.
2026-04-09 Add latest python wheel.
2026-04-10 Add latest 0.2.2 python wheel.
2026-04-10 - Add sensor read exception text to JSON text for debug purposes. - Make unit name configurable via an http push. - Power cycle sensors when starting MCU SW.
2026-04-10 Add latest 0.2.4 python wheel installer.
2026-04-11 If we get an error reading the sensors, power cycle the sensor before trying again.
    [app.py]
2026-04-11 Add latest python wheel installer.
2026-04-11 Added cap on DHT22 power. It's unclear if this is needed and these PCB's have not been built as I'm testing the 1.7 PCB to check if the 220uf 25v cap fixes the sensor read lockup for sensors 2 & 3.
    [temper.kicad_pcb, temper.kicad_sch]
2026-04-15 Add pullup resistors on DHT22 data lines as temp readings were not reliable.
    [temper.kicad_pcb, temper.kicad_sch]
2026-04-24 Spin PCB: Power sensors from 5v (3.3v pullups) to allow sensors to sit on the end of longer cables without locking up.
    [temper.kicad_pcb, temper.kicad_sch]
2026-04-24 Add the latest python wheel.
2026-05-14 Moved C2 on PCB as there was too close to J5
    [temper.kicad_pcb, temper.kicad_sch]
2026-05-14 - Updated gui so that port names are stored per device. - Bump to 0.2.14
2026-06-02 Update to kicad v10
    [temper.kicad_sch]
2026-06-02 - Apply power to DHT22 for latest HW - When a DHT22 read error occurs record this in the temp and humidity values (=read_error string rather than float value).
    [app.py]
2026-06-03 /TON changed to TON for latest SCHEMATIC/PCB
    [temper.kicad_pcb, temper.kicad_sch]
2026-06-03 - Fix incorrect M1 connectivity. - Bump PCB to V2.0
    [temper.kicad_pcb, temper.kicad_sch]
2026-06-03 Ensure sidebar is wide enough to display the X to delete a sensors data if required.
2026-06-03 - Update comments as /TON pin is now TON on latest PCB. - Update 3V3 and 5V rails scale values.
2026-06-05 Now the hardware powers off the sensors correctly return to powercycling the DHT22 temperature sensors in the event of a sensor read error.
    [app.py]
2026-06-07 - Only try to read connected sensor. During startp a check is made for connected DHT22 temp sensors. Only detected sensors are read. If a sensors fails to read a powercycle occurs to recover the situ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
    [app.py]
2026-06-07 - When running temper_db.py ensure the sensor data is logged (if read).
2026-06-08 The follwoing are attempts to stop sensor lockups. - Disable GC during reads, as a gc.collect() during a read may cause DHT22 state machine to lockup. - Add a 1 second delay between each DHT22 device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
2026-06-08 If we read an invalid temperature then raise an error to trigger a power cycle to fix the issue.
    [app.py]
2026-06-19 Add workaround for invalid readings, retry followed by reboot.
    [app.py]
